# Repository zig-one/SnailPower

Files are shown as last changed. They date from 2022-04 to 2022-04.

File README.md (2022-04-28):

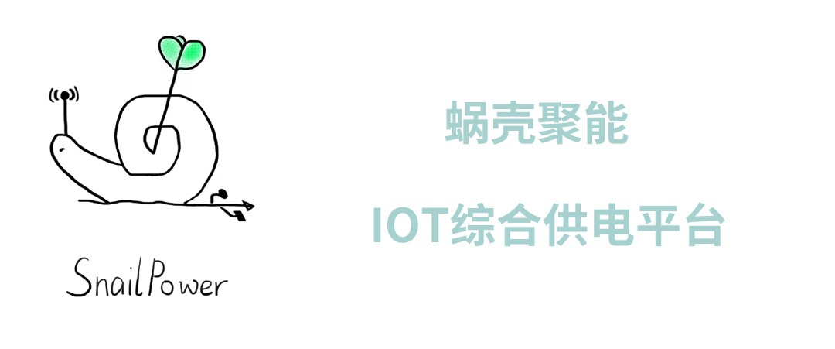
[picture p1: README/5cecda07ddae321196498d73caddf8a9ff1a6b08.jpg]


### 一、项目简介

本项目希望能够提供一个开放、综合的移动设备电源解决方案。

### 二、 立项原因

一块树莓派常常用usb接口直接连充电器供电，导致移动不便，用充电宝供电又会因为电量耗尽而突然关机。很多情况下，例如小气象站，我们希望把东西打包后放到屋外，用太阳能、风能供电，使设备脱离或半脱离有线电源。我们是否能够设计一个综合供电平台，提供各种接口、各种电压的输入，通过变压稳压模块，实现多种电源提供方式无缝切换，并能交互地显示电量呢？

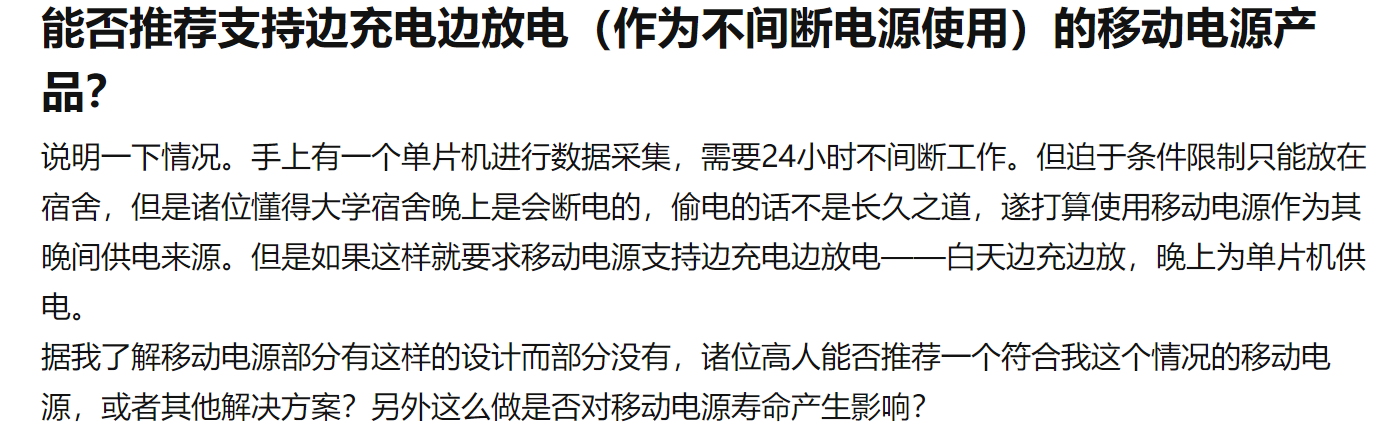
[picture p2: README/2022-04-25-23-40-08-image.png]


我的想法同样也有人想到过。答者们轻易地把它归到ups的推荐。但是普通的ups是220v供电，有较大的功率，未免大材小用。有人建议使用可以边冲边放的充电宝，但也有人批驳这样会损坏充电宝，而我拿手头的华为充电宝尝试时发现在充放切换的过程中会出现一小段的断电时间，会让设备不能正常工作。也一部分定制的ups，例如给小路由器专用的ups，价格比较便宜，电压挡位也有多种选择，这个应该可以满足题主的需求。不过要想接受不同电压的输入还是力有所不及。那么一个能够灵活接受输入、进行输出的平台应该能够配得上综合二字了吧。巧了，升降压模块还真能宽电压输入，指定电压输出。

### 三、电路设计

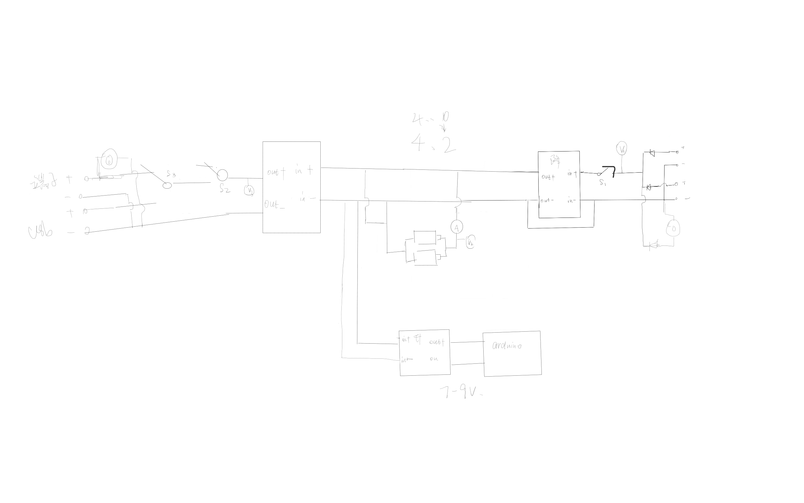
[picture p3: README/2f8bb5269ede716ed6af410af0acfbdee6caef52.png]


### 四、接线和蓝牙串口交互设计



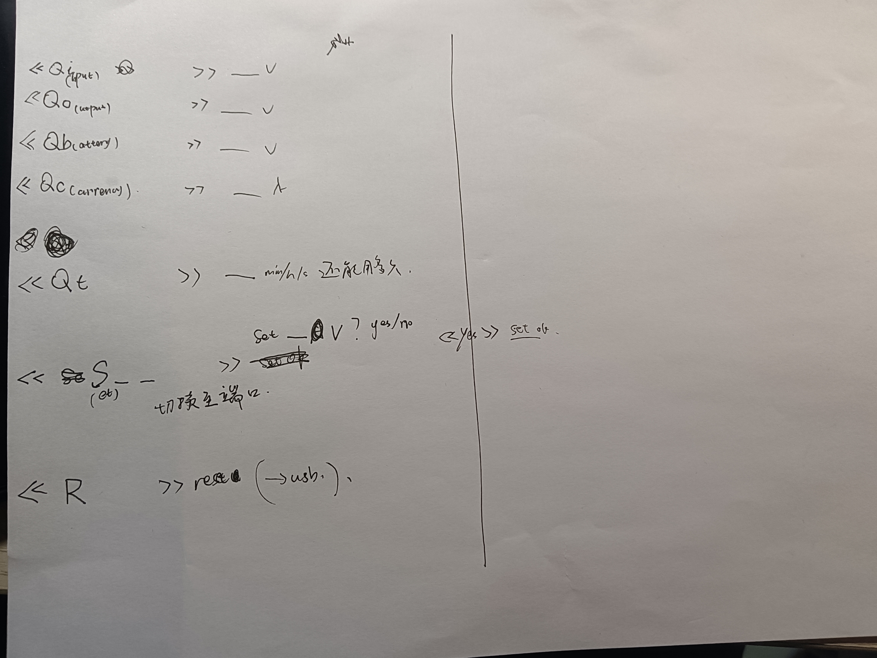
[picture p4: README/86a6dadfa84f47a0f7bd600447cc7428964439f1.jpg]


### 五、外壳设计

一个简易的二层盒状外壳,引出两个端子和两个type-C usb口。由solidworks建模，USTC创新实践基地3D打印。

### 六、程序设计

使用arduino平台，使用ACS712和SoftwareSerial库，实现读取电流和蓝牙串口通信。

### 七、不足

设计时，加入了继电器，但是发现arduino的另外供电的升压班似乎带不动，每次会噼噼啪啪地来回开关闭合。

设计时，加入了二极管整流，但是发现降压后的5V的电压只剩下了4.3V而这时的电压与锂电池的充电电压过于接近导致降压板一降压就只有3V多。于是将电压降到2V再升压给电池供电，但是电路工作得也很不稳定，降压板会发出响声（电感的啸叫），输出的电压也跳动不定。不太敢用，怕把电池充炸了。

设计时，使用了arduino和蓝牙模块，但在实际点亮时，测得功率接近1W,这似乎和查到的数据相比大得离谱。

设计时，想用X9C数字电位器来代替旋转电位器，并用adc采集电压进行闭环控制，进而可以通过蓝牙调节电压。结果烧掉了两个半X9C和弄坏了两块升压板，升压板有时还会出现40V电压，强行断开过热的X9C时还会有电火花。

...

技术能力不太够，核心技术也不了解。拼装并不是一个简单的活:p

不过就当留个坑，将来有能力可以再填。

### 八、幻想发散

2022.4.26

这个题目是我在海边玩后回家的路上想到的。傍晚阳光依然灿烂，我就再想做一些什么好呢，那么好的太阳总该来一些太阳能板，又想到前几天用树莓派时被电源线束缚的种种不便。那么IOT设备们要是有一个可移动、可交互的电源会有多好。我是这样想的，那就这样做吧，而且这个题目进可攻退可守，实在不行买一个小UPS也能凑数么。不过在开做的时候还是挑战了一下，我们小组自行设计了电路连接，采购了元件。刘万如同学设计了盒子的外壳，并在创新实践基地叶回春老师的指导下完成了3D打印。刘凯阳同学帮忙焊接了电路，制作了汇报用的ppt,以及指导视频剪辑。经过了一个多学期艰难~~磨蹭~~的讨论采购组装，最终完成了搭建，尽管不太可靠(汗)。不过也算是有一个小成果。看着它不禁会想到电影《三傻大闹宝莱坞》里兰彻的病毒号变压器，啊哈，看了我还得再学学再设计设计。

### 九、关于SnailPower

目前还是一个不完整的项目，如果愿意帮助填坑，欢迎提ISSUE和PULL REQUEST。

个人联系方式 1260492908@qq.com

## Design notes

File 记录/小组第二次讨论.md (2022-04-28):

## 第二次讨论 &原型试验

2021.12.7

#### 完成

1.从充电宝到升压器到电池到降压器再给手机充电的流程，并用LED侦测有电

```mermaid
graph LR
A[输入]-->B{升压}
B-->D(( ))
E(电池).-D
D-->F{降压}
F-->G[输出]
style A fill:#2ff,fill-opacity:0.1,stroke:#faa,stroke-width:4px
style D stroke:#000,stroke-width:2px;

```

2.对室外太阳光照进行不完全测定（mV，mA）



#### 未完成

1.电池买得太大，电池盒放不下

2.充电电流可能过大

3.杜邦线承载电流小，需要更换电线

#### 计划中

1.作品命名、logo设计

2.外壳封装

3.与各类型电源输入可靠性测试

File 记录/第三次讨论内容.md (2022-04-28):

## 第三次讨论计划

#### 1.进行固定电路的焊接与拧紧

#### 2.分配接下来的任务

    1.用模拟输入测电池的工作状态——电压、电流、电量百分比

    2.蓝牙通讯    

    3.手机蓝牙连接与图形化输出

    4.基于继电器的简单电池保护

    5.命名与logo设计

    6.外壳设计

    7.封装测试

#### 3.再次测太阳。。

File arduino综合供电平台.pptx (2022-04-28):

## 树莓派 & arduino 综合供电方案

卢星宇

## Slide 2

- 背景
- 困难
  - 能力随机性
  - 解决经历
  - 。。。
  - 买到造
  - 你在支配咖啡但咖啡没法支配你

## 设计初心

一块树莓派常常用usb借口直接连充电器供电，导致移动不便，用充电宝供电又会因为电量耗尽而突然关机。想做个气象站把东西打包后放到屋外，希望用太阳能、风能供电。我们是否能够设计一个综合供电平台，提供各种接口的输入，通过变压稳压模块，实现多种电源提供方式无缝切换，并为用电设备提供电量显示端口。

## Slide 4

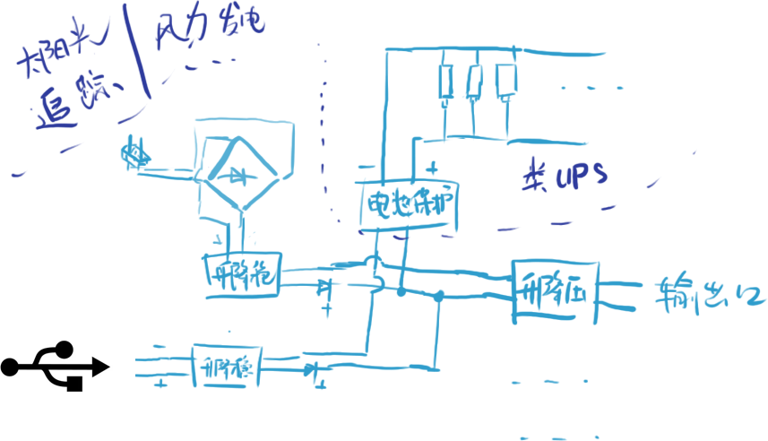
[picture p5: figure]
未标题-1

## 本课题进可攻退可守

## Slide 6

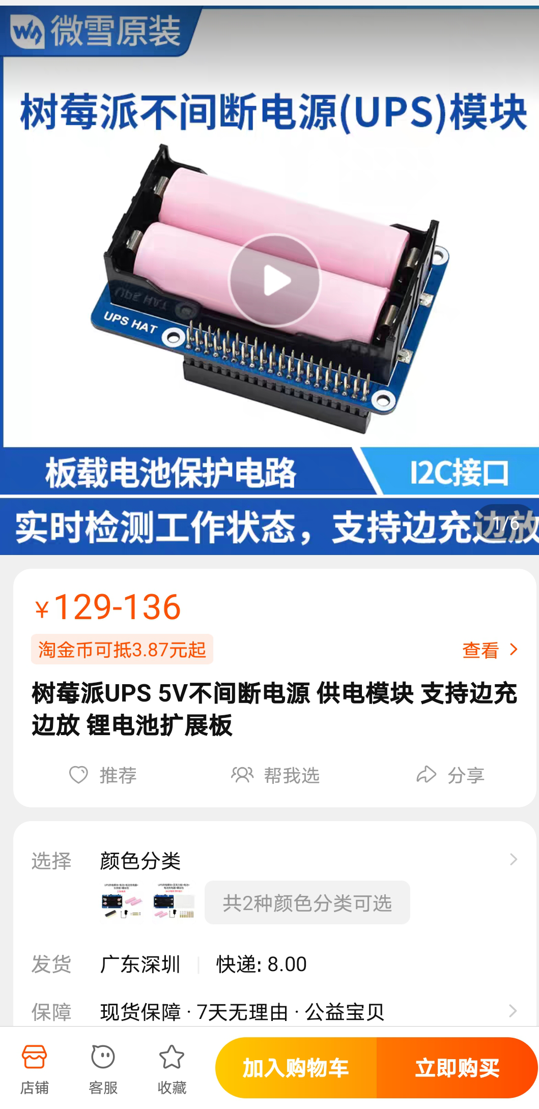
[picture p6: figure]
Screenshot_20211024_221112

最低限度非常容易实现，只要氪金毫无难度。

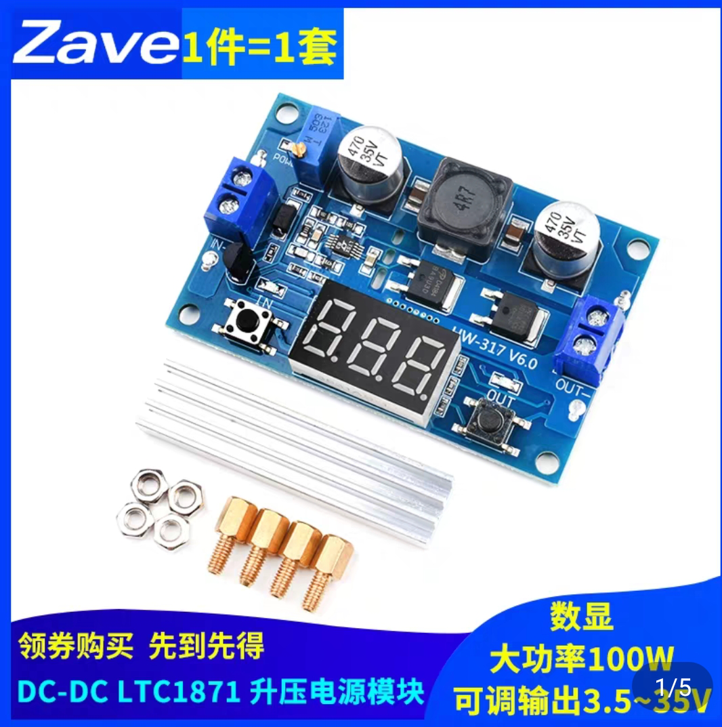
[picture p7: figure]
Screenshot_20211024_221148

守

## 进击

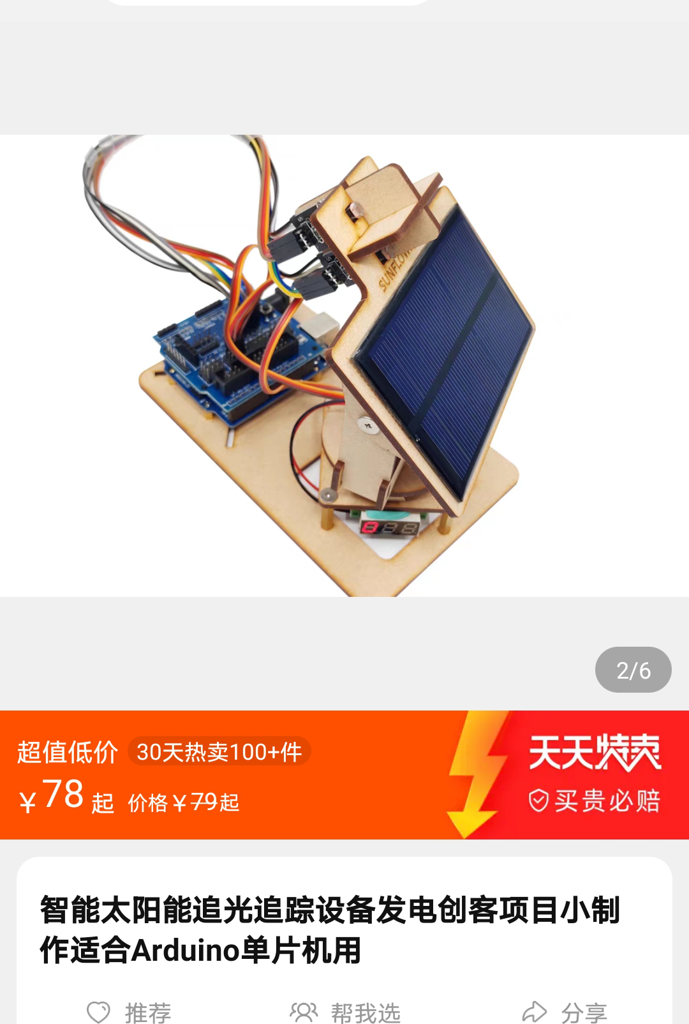
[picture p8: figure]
Screenshot_20211024_221124

1.学习电路知识
2.探究弱电直流升降压稳压的方法
3.设计和组装电路
4.学习锂电池的使用（保养）
5.为将来把树莓派或arduino丢到一个荒无人烟没有电网的角落自生自灭做准备

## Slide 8

END.

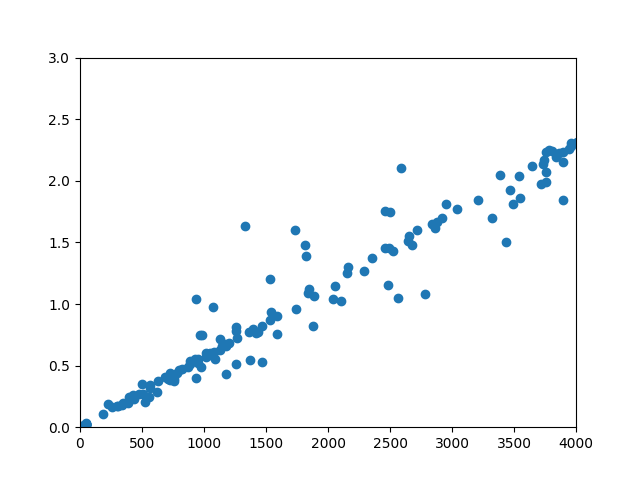
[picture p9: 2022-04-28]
VA/battery/A/Figure_1.png

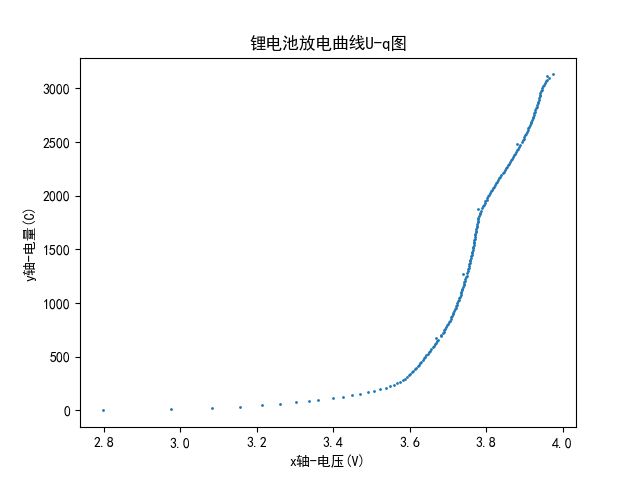
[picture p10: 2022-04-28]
VA/battery/A/q_U.png

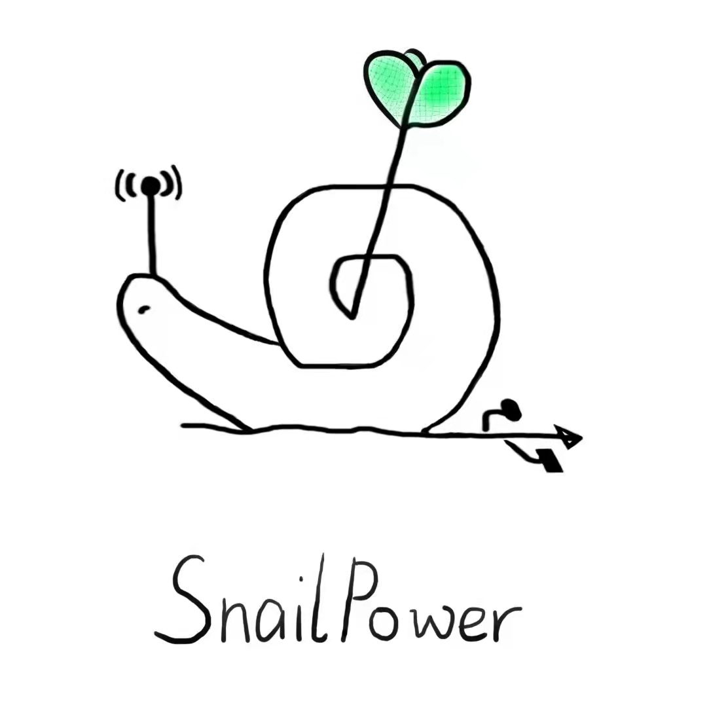
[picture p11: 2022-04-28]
README/2022-04-25-23-36-32-image.png

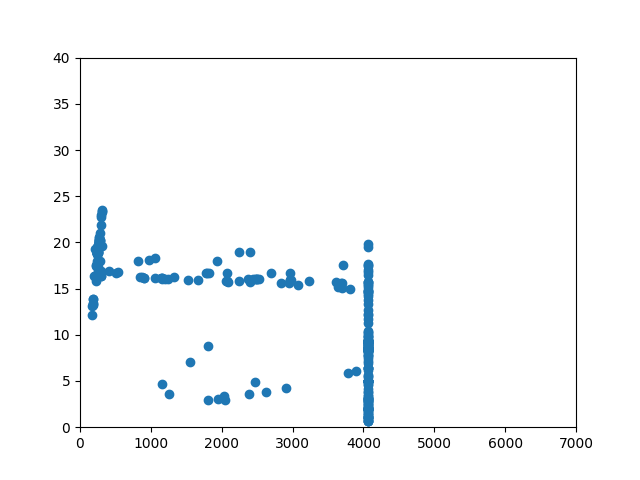
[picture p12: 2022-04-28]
VA/sun/Figure_14.png

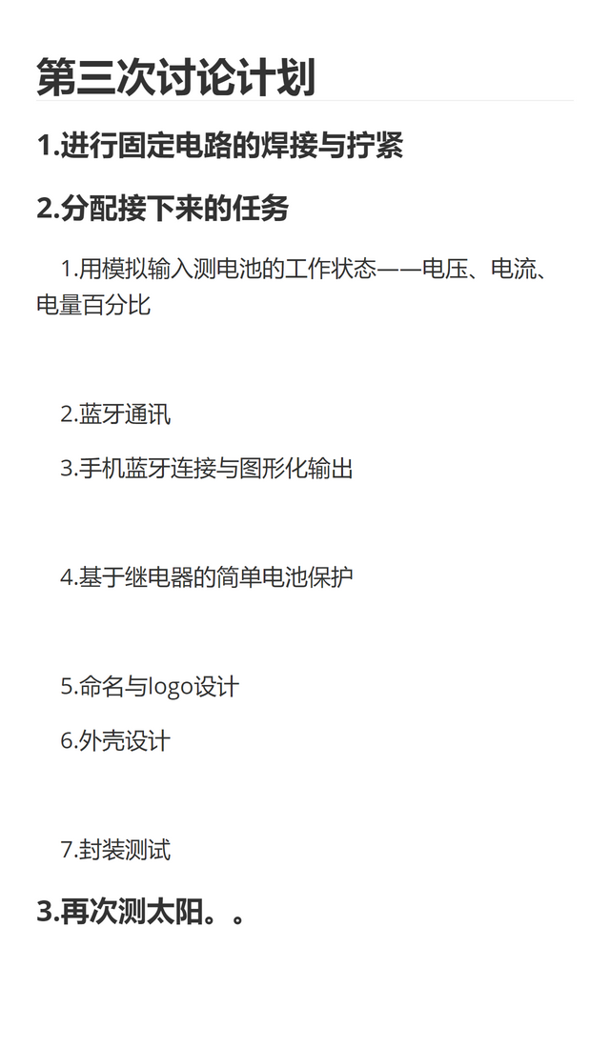
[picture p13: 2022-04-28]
记录/第三次讨论内容.png

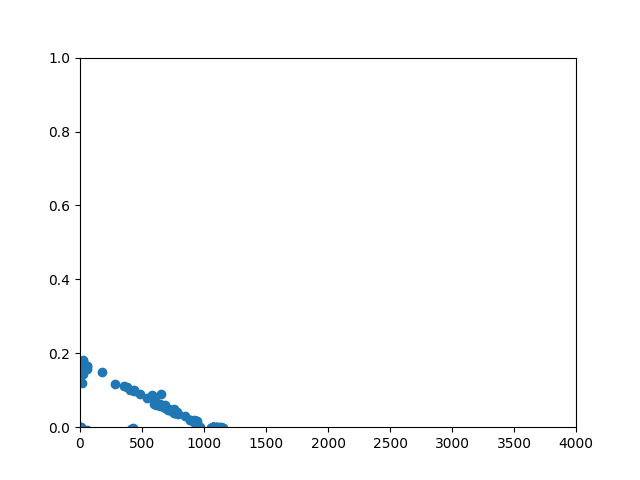
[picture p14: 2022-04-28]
VA/sun/Figure_2.png

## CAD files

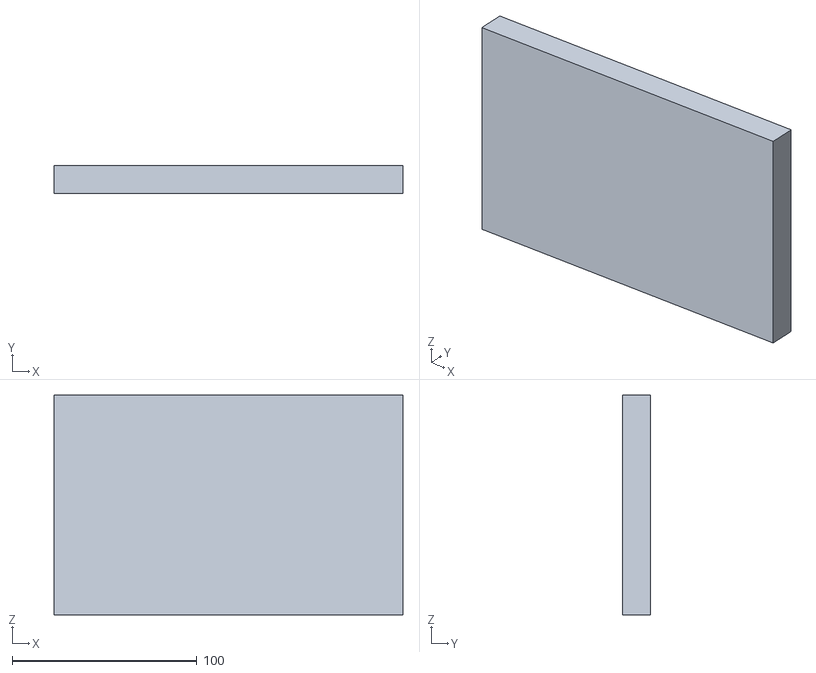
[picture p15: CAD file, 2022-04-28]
3D_part/盖.STL
189.0 x 15.0 x 119.0

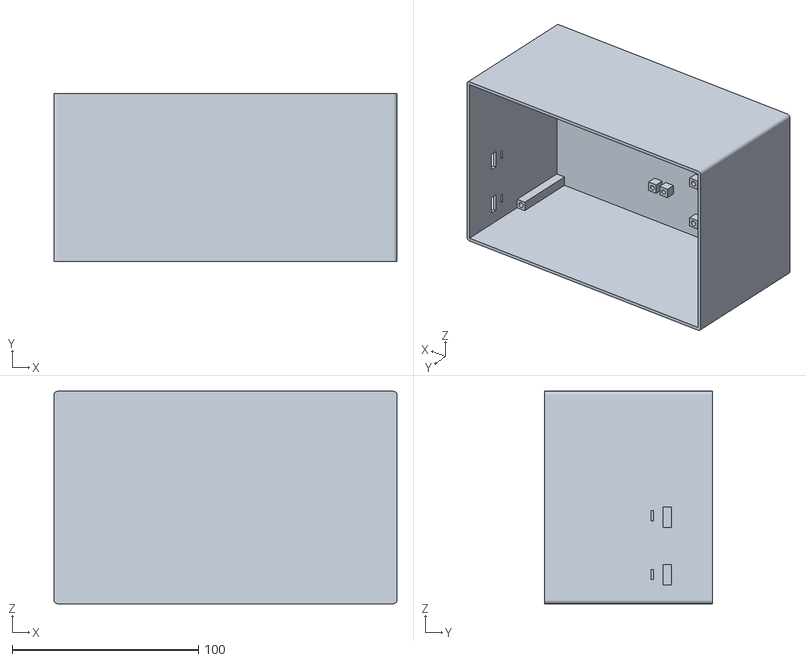
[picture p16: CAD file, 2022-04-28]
3D_part/盒底.STL
184.0 x 90.0 x 114.0

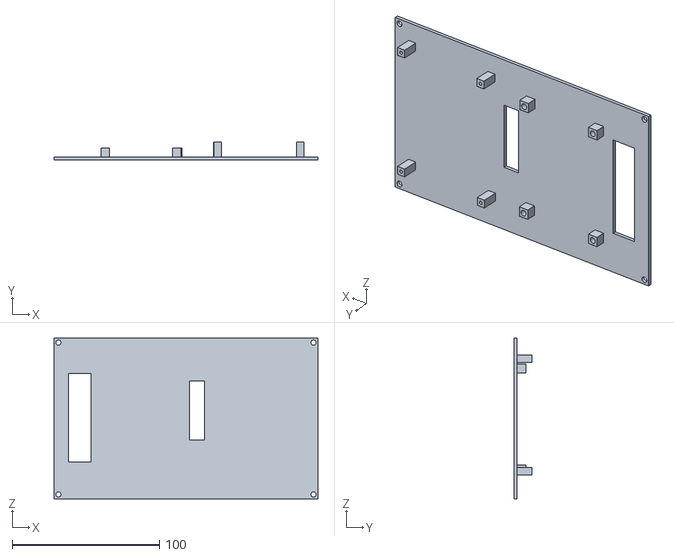
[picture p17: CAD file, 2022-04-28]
3D_part/中间.STL
179.0 x 12.0 x 109.0

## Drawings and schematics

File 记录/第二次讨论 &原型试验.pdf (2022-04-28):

## 第二次讨论 &原型试验

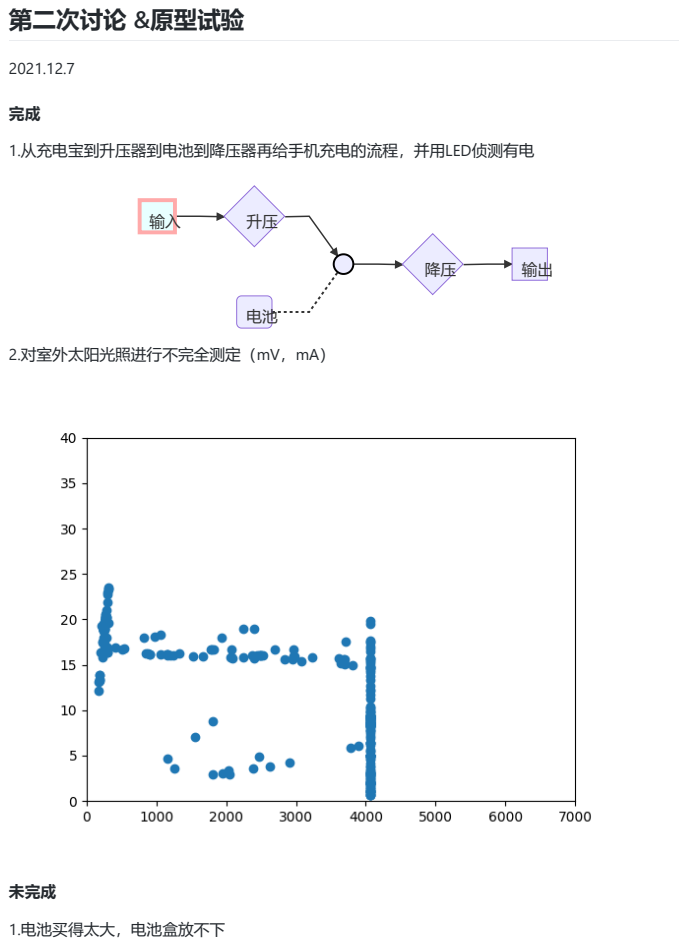
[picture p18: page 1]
1.从充电宝到升压器到电池到降压器再给手机充电的流程，并用LED侦测有电; 未完成; 1.电池买得太大，电池盒放不下

2.对室外太阳光照进行不完全测定（mV，mA）

2.充电电流可能过大

3.杜邦线承载电流小，需要更换电线

计划中

1.作品命名、logo设计

2.外壳封装

3.与各类型电源输入可靠性测试

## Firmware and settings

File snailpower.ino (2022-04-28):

#include <ACS712.h>
#include <SoftwareSerial.h> // 引用库

#define DEFAULT_USB_VOLTAGE 5
#define VOLTAGE_TOLERENCE 0.5
// #define DEBUG

#define PIN_BT_RXD 8
#define PIN_BT_TXD 9
#define PIN_POTENTIOMETERS_UD 4
#define PIN_POTENTIOMETERS_CS 5
#define PIN_POTENTIOMETERS_INC 3
// V1
#define PIN_INPUT_VOLTAGE A0
// V2
#define PIN_BATTERY_VOLTAGE A1
// V3
#define PIN_OUTPUT_VOLTAGE A2

#define PIN_BATTERY_CUTTENT A3

// bluetooth module
SoftwareSerial BT(PIN_BT_TXD, PIN_BT_RXD); // 接HC05发送脚与D8接口连接，HC05接收脚与D9接口连接
char Bt_val;                               // 存储接收的数据

// ACS127
ACS712 ACS(ACS712_05B, PIN_BATTERY_CUTTENT);

int step = 0;


void read_BT()
{
  // 把蓝牙模块接收到的数据发送到串口监视器
  if (BT.available())
  {
    Bt_val = BT.read();
#ifdef DEBUG
    Serial.print(Bt_val);
#endif

  }




#ifdef DEBUG
  // 把串口监视器接收到的数据发送给蓝牙模块
  if (Serial.available())
  {
    Bt_val = Serial.read();
    BT.print(Bt_val);
  }
#endif
}

class Snail_Power
{
  public:

    double vi = 0, vb = 0, vo = 0, cu = 0, percent = 0;
    unsigned long time_last = 0, time_left = 0;


    Snail_Power()
    {

    }

    double get_voltage(uint8_t pin)
    {
      double v = 0;
      for (int i = 0; i < 5; i++)
        v += analogRead(pin) * 5.0 / 1024;
      return v / 5.0;
    }

    void get_status()
    {
      get_output_voltage();
      get_input_voltage();
      get_battery_voltage();
//      get_battery_current();
      get_remaining_power();
    }

    bool usb_safe()
    {
      return vo >= 4.7 && vo <= 5.3;
    }

    double get_input_voltage()
    {
      //TODO:design
      vi = get_voltage(PIN_INPUT_VOLTAGE) * 5.67; //分压计算
      String s="输入电压:"+String(vi);
      BT.print(s);
      return vi;
    }

    double get_output_voltage()
    {
      vo = get_voltage(PIN_OUTPUT_VOLTAGE) * 5.67-0.74; //分压计算
      if(vo<0)vo=0;
      String s="输出电压:"+String(vo);
      BT.print(s);

      return vo;
    }

    double get_battery_voltage()
    {
      vb = get_voltage(PIN_BATTERY_VOLTAGE) * 5.67; //分压计算
      String s="电池电压:"+String(vb);
      BT.print(s);

      return vb;
    }

    double get_battery_current()
    {
      cu = ACS.getCurrentDC();
      String s=String("电流:")+cu+"A";
      BT.print(s);

    }

    double get_remaining_power()
    {

      // TODO: fix
      //
      double percent2 = 259.36 * vb * vb - 1716.6 * vb + 2831.2;

      // TODO:be careful
      if (fabs(percent2 - percent) >= 0.5)
      {
        unsigned long time_now = millis();
        if (time_now > time_last) // overflow of time
        {
          time_left = percent2 / (percent2 - percent) * (time_last - time_now) / 1000.0 / 60; // ms->min
          time_last = time_now;
          percent = percent2;
        }
      }
      return percent2;
    }
    double get_time_left()
    {
      return time_left;
    }
} SnailPower;




void setup()
{
#ifdef DEBUG
  Serial.begin(9600);
  Serial.println("BT is ready!");
  // 如果是HC-06，改成38400；
#endif
  BT.begin(9600);
  pinMode(PIN_BATTERY_CUTTENT, INPUT);
  pinMode(PIN_BATTERY_VOLTAGE, INPUT);
  pinMode(PIN_INPUT_VOLTAGE, INPUT);
  pinMode(PIN_OUTPUT_VOLTAGE, INPUT);

}

void loop()
{
  delay(1000);
  read_BT();
  SnailPower.get_status();
}

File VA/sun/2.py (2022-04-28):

#导入模块
import serial 
import matplotlib.pyplot as plt
import numpy as np

x=[]
y=[]
plt.ion()  # 开启交互模式
plt.subplots()
#xy轴
plt.xlim(-1, 1000)
plt.ylim(-1, 1000)
ax = plt.scatter(x, y)

try:
  #端口，GNU / Linux上的/ dev / ttyUSB0 等 或 Windows上的 COM3 等
  portx="COM4"
  #波特率，标准值之一：50,75,110,134,150,200,300,600,1200,1800,2400,4800,9600,19200,38400,57600,115200
  bps=9600
  #超时设置,None：永远等待操作，0为立即返回请求结果，其他值为等待超时时间(单位为秒）
  timex=5
  # 打开串口，并得到串口对象
  ser=serial.Serial(portx,bps,timeout=timex)
  print("串口详情参数：", ser)



  print(ser.port)#获取到当前打开的串口名
  print(ser.baudrate)#获取波特率


  while True:
         if ser.in_waiting:
             str=ser.read(ser.in_waiting ).decode("gbk")
             if(str=="exit"):#退出标志
                 break
             else:
                print("收到数据：",str)
                plt.clf()     # 清空画布
                plt.xlim(0, 7000)      # 因为清空了画布，所以要重新设置坐标轴的范围
                plt.ylim(0, 40)
                strlist = str.split('|')	# 用逗号分割str字符串，并保存到列表
                #print("\n",strlist[0])
                x.append(float(strlist[0]))
                y.append(float(strlist[1]))
                plt.scatter(x, y)
                plt.pause(0.2)
               
  print("---------------")
  ser.close()#关闭串口


except Exception as e:
    print("---异常---：",e)
